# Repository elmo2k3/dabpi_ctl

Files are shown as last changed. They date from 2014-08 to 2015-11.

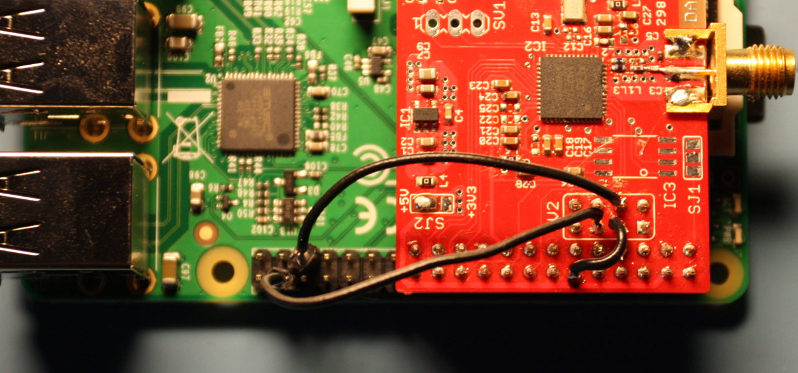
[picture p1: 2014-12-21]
doc/pics/a_b_plus.jpg

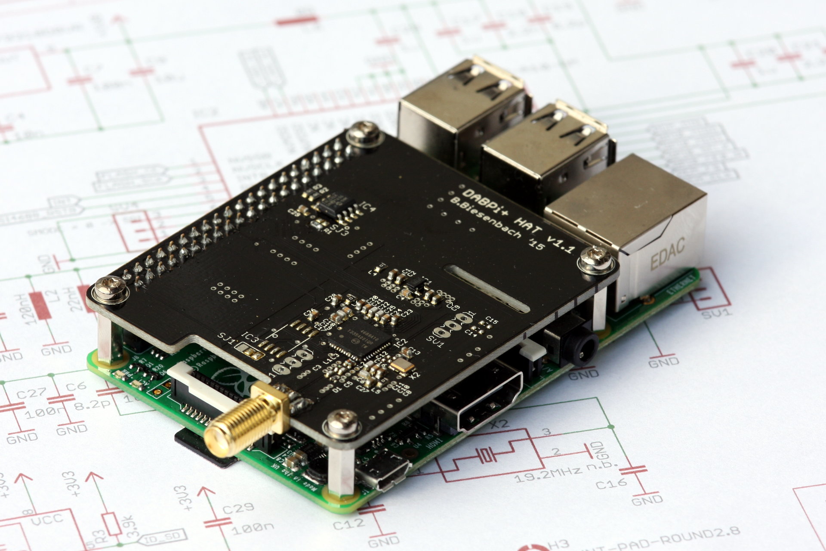
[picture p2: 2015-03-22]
doc/pics/dabpi+_v11_scaled.jpg

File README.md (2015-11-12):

# dabpi_ctl - RPi fm/fmhd/dab receiver control interface

![Image of DABPi+ v11 PCB]
(https://github.com/elmo2k3/dabpi_ctl/blob/master/doc/pics/dabpi+_v11.jpg)
DABPi+ for Raspberry Pi A+/B+ versions. Pi2 not tested yet.
![Image of DABPi v1 PCB]
(https://github.com/elmo2k3/dabpi_ctl/blob/master/doc/pics/dabpi_v1.jpg)
DABPi for older Raspberry Pi A/B versions.

## News

12.4.2015
Works on Pi2 now. New Kernel 3.18.11-v7+ included for Pi2.

## Warning

!!! Firmware files removed due to license issues !!!

This project is beta. A lot of features are still missing.

## Requirements

You need a RPi that has the option to mount the I2S extension header.
![Image of RPi with soldered I2S extension header]
(https://github.com/elmo2k3/dabpi_ctl/blob/master/doc/pics/IMG_0292.JPG)

Get the firmware package for Si4688 from Silabs.

Be sure to enable SPI in raspi-config.

Install wiringPi library. See http://wiringpi.com/download-and-install/

To get the audio you need to install a new kernel. It can be compiled from here
https://github.com/elmo2k3/linux or use the precompiled image. For the precompiled binarys, see the Install section.

## RPi A+/B+ instructions
![Image of RPi B+ with additional cables]
(https://github.com/elmo2k3/dabpi_ctl/blob/master/doc/pics/a_b_plus.jpg)

Connect P5 header pins 3,4,5 to GPIO header pins 12,35,38.

## Install

There is a very simple install script for a fresh raspian now (where there is nothing to be damaged).

```bash
wget https://github.com/elmo2k3/dabpi_ctl/raw/master/install_on_fresh_raspbian.sh
chmod a+x install_on_fresh_raspbian.sh
./install_on_fresh_raspbian.sh
```
This will install the commandline tool to /home/pi/dabpi_ctl

Unpack the firmware files (get it from silabs or ask me) into /home/pi/dabpi_ctl/firmware

### Manual Install

Get and compile the source code:

```bash
git clone https://github.com/elmo2k3/dabpi_ctl
cd dabpi_ctl
make
```
If you want to use the precompiled kernel, it can be found in the kernel/ directory.

```bash
sudo cp kernel/Image /boot/kernel.img
sudo rm -rf /lib/modules
sudo rm -rf /lib/firmware
sudo tar -C / -xvzf kernel/lib.tar.gz
```
Edit /etc/modules
```bash
bcm2708_dmaengine
snd-bcm2835
```
After a reboot load the module.

```bash
sudo modprobe snd-soc-rpi-dabpi
```
You should see this in the kernel log:
```bash
pi@raspberrypi ~/dabpi_ctl $ dmesg | tail -n1
[ 2435.067966] snd-dabpi snd-dabpi.0:  si468x-hifi <-> bcm2708-i2s.0 mapping ok
pi@raspberrypi ~/dabpi_ctl $
```

## Usage

Run dabpi_ctl:

```bash
[bjoern@x200 user_program]$ ./dabpi_ctl
usage: ./dabpi_ctl [-a|-b]
  -a             init DAB mode
  -b             init fm mode
  -c frequency   tune frequency in FM mode
  -d             fm status
  -e             dab status
  -f service     start service of dab service list
  -g             get dab service list
  -i channel     tune to channel in dab frequency list
  -j region      set frequency list
                    0   Baden-Wuertemberg
                    1   Bayern
                    2   Berlin-Brandenburg
                    3   Bremen
                    4   Hamburg
                    5   Hessen
                    6   Mecklenburg-Vorpommern
                    7   Niedersachsen
                    8   Nordrhein-Westfalen
                    9   Rheinland-Pfalz
                    10  Saarland
                    11  Sachsen
                    12  Sachsen-Anhalt
                    13  Schleswig-Holstein
                    14  Thueringen
                    15  Suedtirol (Italien)
                    16  Schweiz
  -k region      scan frequency list
  -l up|down     fm seek next station
  -m             fm rds status
  -n             dab get audio info
  -o             dab get subchannel info
  -s             get sys state (fm,dab,am...)
  -h             this help
```

### Audio output

To test audio output, redirect it from capture to playback device:

```bash
alsaloop -C hw:1,0
```
Stream audio to another linux machine over ssh:

```bash
ssh pi@PI-IP-ADDRESS 'arecord -D hw:1,0 -f dat -' | aplay -f dat -
```

### Examples

Enter fm mode:

```bash
pi@raspberrypi ~/dabpi_ctl $ sudo ./dabpi_ctl -b
si46xx_init_mode_fm()
si46xx_get_sys_state answer: 800000c001ff
si46xx_get_part_info answer: 800000c0000000005012000000005012000000000100
[...]
si46xx_fm_tune_freq(98500)
808000c0
pi@raspberrypi ~/dabpi_ctl $
```

Tune to radio station 106.700MHz:

```bash
pi@raspberrypi ~/dabpi_ctl $ sudo ./dabpi_ctl -c 106700
si46xx_fm_tune_freq(106700)
808000c0
pi@raspberrypi ~/dabpi_ctl $
```

Enter DAB mode and scan all channels in the list for NRW:

```bash
pi@raspberrypi ~/dabpi_ctl $ sudo ./dabpi_ctl -a -k 8
si46xx_init_mode_dab()
[...]
si46xx_dab_tune_freq(0): 818000c0
si46xx_dab_digrad_status(): Channel 0: ACQ: 1 RSSI: 45 SNR: -10 Name: DR Deutschland
si46xx_dab_tune_freq(1): 818000c0
si46xx_dab_digrad_status(): Channel 1: ACQ: 1 RSSI: 41 SNR: -10 Name: Radio fuer NRW
pi@raspberrypi ~/dabpi_ctl $
```

Select DAB channel:

```bash
pi@raspberrypi ~/dabpi_ctl $ sudo ./dabpi_ctl -i 1
si46xx_dab_tune_freq(0): 818000c0
pi@raspberrypi ~/dabpi_ctl $
```

Get ensemble information:

```bash
pi@raspberrypi ~/dabpi_ctl $ sudo ./dabpi_ctl -g
si46xx_dab_get_digital_service_list()
List size:     370
List version:  227
Services:      13
Num:  0  Service ID: e0d01005  Service Name: WDR-INFO          Component ID: 49162
                                                               Component ID: 49162
Num:  1  Service ID:     109d  Service Name: Domradio          Component ID: 12
                                                               Component ID: 0
Num:  2  Service ID: e0d01006  Service Name: WDR-TPEG          Component ID: 49163
                                                               Component ID: 0
Num:  3  Service ID:     d394  Service Name: WDR 4             Component ID: 14
                                                               Component ID: 0
Num:  4  Service ID:     df92  Service Name: VERA              Component ID: 8
                                                               Component ID: 0
Num:  5  Service ID:     d391  Service Name: 1LIVE             Component ID: 1
                                                               Component ID: 0
Num:  6  Service ID:     d395  Service Name: WDR 5             Component ID: 4
                                                               Component ID: 0
Num:  7  Service ID:     d496  Service Name: FUNKHAUS EUROPA   Component ID: 5
                                                               Component ID: 0
Num:  8  Service ID: e0d01004  Service Name: WDR-EPG           Component ID: 49161
                                                               Component ID: 0
Num:  9  Service ID:     df95  Service Name: KinderRadioKanal  Component ID: 2
                                                               Component ID: 0
Num: 10  Service ID:     df91  Service Name: 1LIVE diggi       Component ID: 3
                                                               Component ID: 0
Num: 11  Service ID:     1462  Service Name: RADIO IMPALA      Component ID: 13
                                                               Component ID: 0
Num: 12  Service ID:     d392  Service Name: WDR 2             Component ID: 7
                                                               Component ID: 0
pi@raspberrypi ~/dabpi_ctl $
```

Start one of the services in ensemble:

```bash
pi@raspberrypi ~/dabpi_ctl $ sudo ./dabpi_ctl -f 5
si46xx_dab_get_digital_service_list()
List size:     370
List version:  227
Services:      13
Num:  0  Service ID: e0d01005  Service Name: WDR-INFO          Component ID: 49162
                                                               Component ID: 49162
[...]
Starting service 1LIVE            d391 1
pi@raspberrypi ~/dabpi_ctl $
```

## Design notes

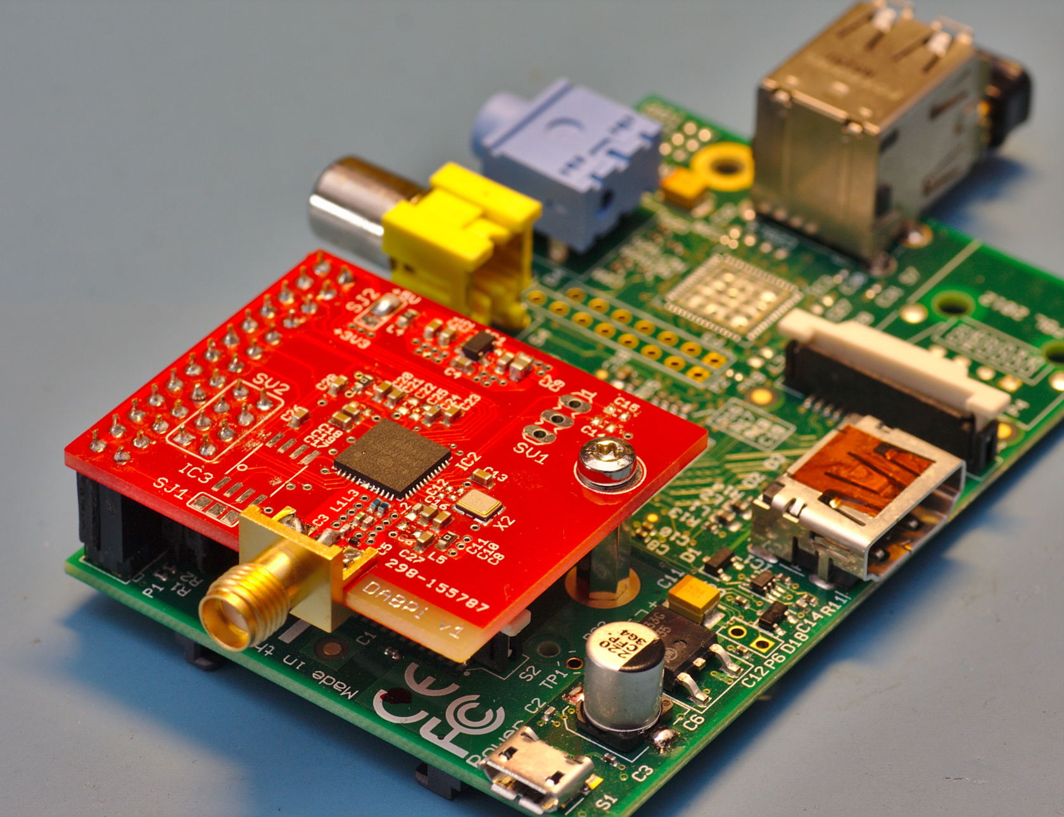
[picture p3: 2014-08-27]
doc/pics/dabpi_v1.jpg

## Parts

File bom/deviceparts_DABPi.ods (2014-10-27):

#name | description | footprint | total_mount_quantity | suppliers | supplierpartnrs | single_prices | total_prices
0R 0402 | MCMR04X000 PTL | R_0603 | 1 | Farnell | 2072513 | $0.01 | $0.01
10nF 0603 25V X7R | MC0603B103K250CT | C_0603 | 1 | Farnell | 1759022 | $0.01 | $0.01
10uF 0603 6.3V X5R | C0603C106M9PACTU | C_0603 | 1 | Farnell | 1288201 | $0.23 | $0.23
120NH 110MA 0402 |  | L_0402 | 1 | Digikey,Farnell | 490-4091-1-ND,2212473 | $0.23,$0.11 | $0.23,$0.11
150pF 0603 | MC0603N151J500CT | C_0603 | 4 | Farnell | 1759068 | $0.00 | $0.00
18NH 300MA 0402 |  | L_0402 | 1 | Digikey,Farnell | 490-2626-1-ND,1343084 | $0.05,$0.06 | $0.05,$0.06
19.2MHZ,3.2 X 2.5 MM | CRYSTAL 19.2MHZ 10PF SMD |  | 1 | Digikey,Farnell | 300-8228-1-ND,1842063 | $1.37,$0.73 | $1.37,$0.73
2.2nF 0603 50V X7R | MC0603B222K500CT | C_0603 | 4 | Farnell | 1759093 | $0.01 | $0.04
22NH 3% 0402 |  | L_0402 | 1 | Digikey,Farnell | 490-6788-1-ND,1711784 | $0.24,$0.05 | $0.24,$0.05
8.2pF 0603 50V C0G | C0603C829C5GACTU | C_0603 | 7 | Farnell | 1865471 | $0.01 | $0.07
Abstandshalter Hex M2.5 11MM |  |  | 1 | Farnell | 1466760 | $0.34 | $0.34
DABPi v1Leiterkarte |  |  | 1 | Iteadstudio | 2 | $2.00 | $2.00
ESD9L5.0ST5G | TVS ESD PROT ELT 5V SOD-923 | SOD923 | 1 | Digikey,Farnell | ESD9L5.0ST5GOSCT-ND,1651639 | -,$0.42 | -,$0.42
SI4688-A10-GM |  | QFN48 | 1 | Arrow | SI4688-A10-GM | $10.00 | $10.00
SMA Buchse PCB |  |  | 1 | Digikey,Farnell | CONSMA003.062-ND,1909295 | $2.77,$3.35 | $2.77,$3.35
TPS79318DBVR | IC REG LDO 1.8V 0.2A SOT23-5 | SOT23-5 | 1 | Digikey,Farnell | 296-12155-1-ND,1652374 | $0.69,$0.91 | $0.69,$0.91

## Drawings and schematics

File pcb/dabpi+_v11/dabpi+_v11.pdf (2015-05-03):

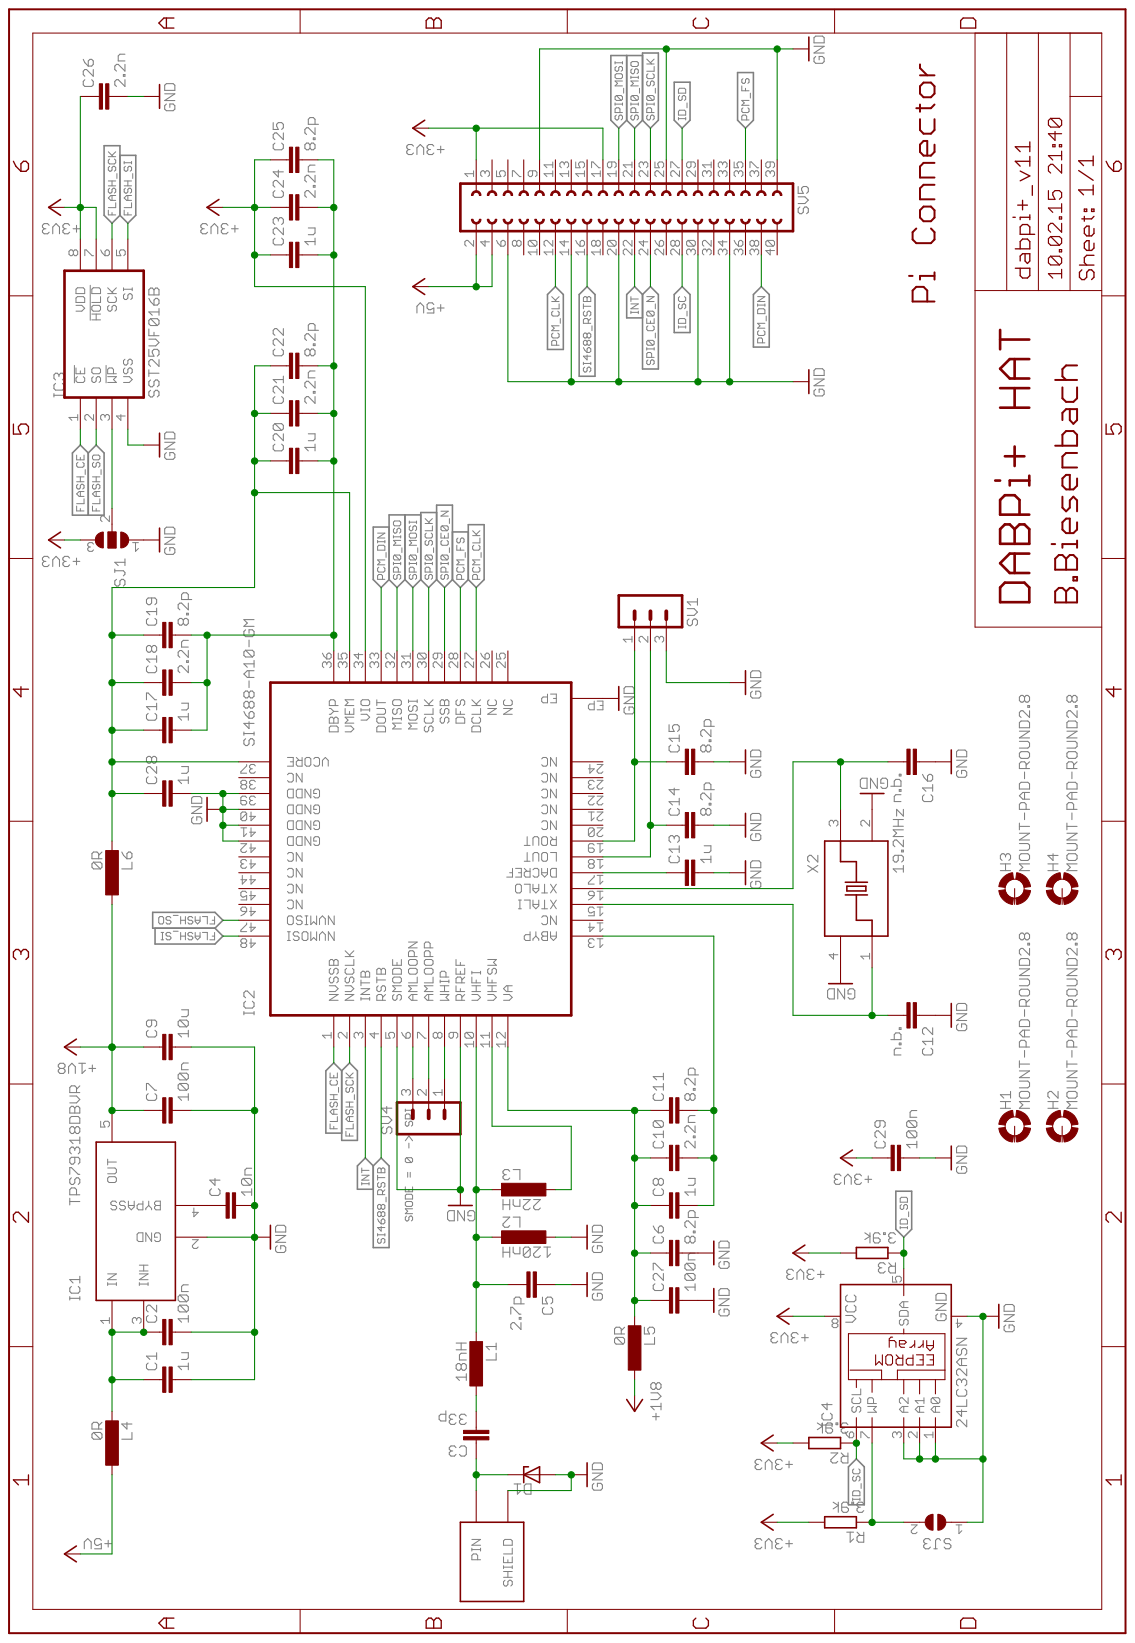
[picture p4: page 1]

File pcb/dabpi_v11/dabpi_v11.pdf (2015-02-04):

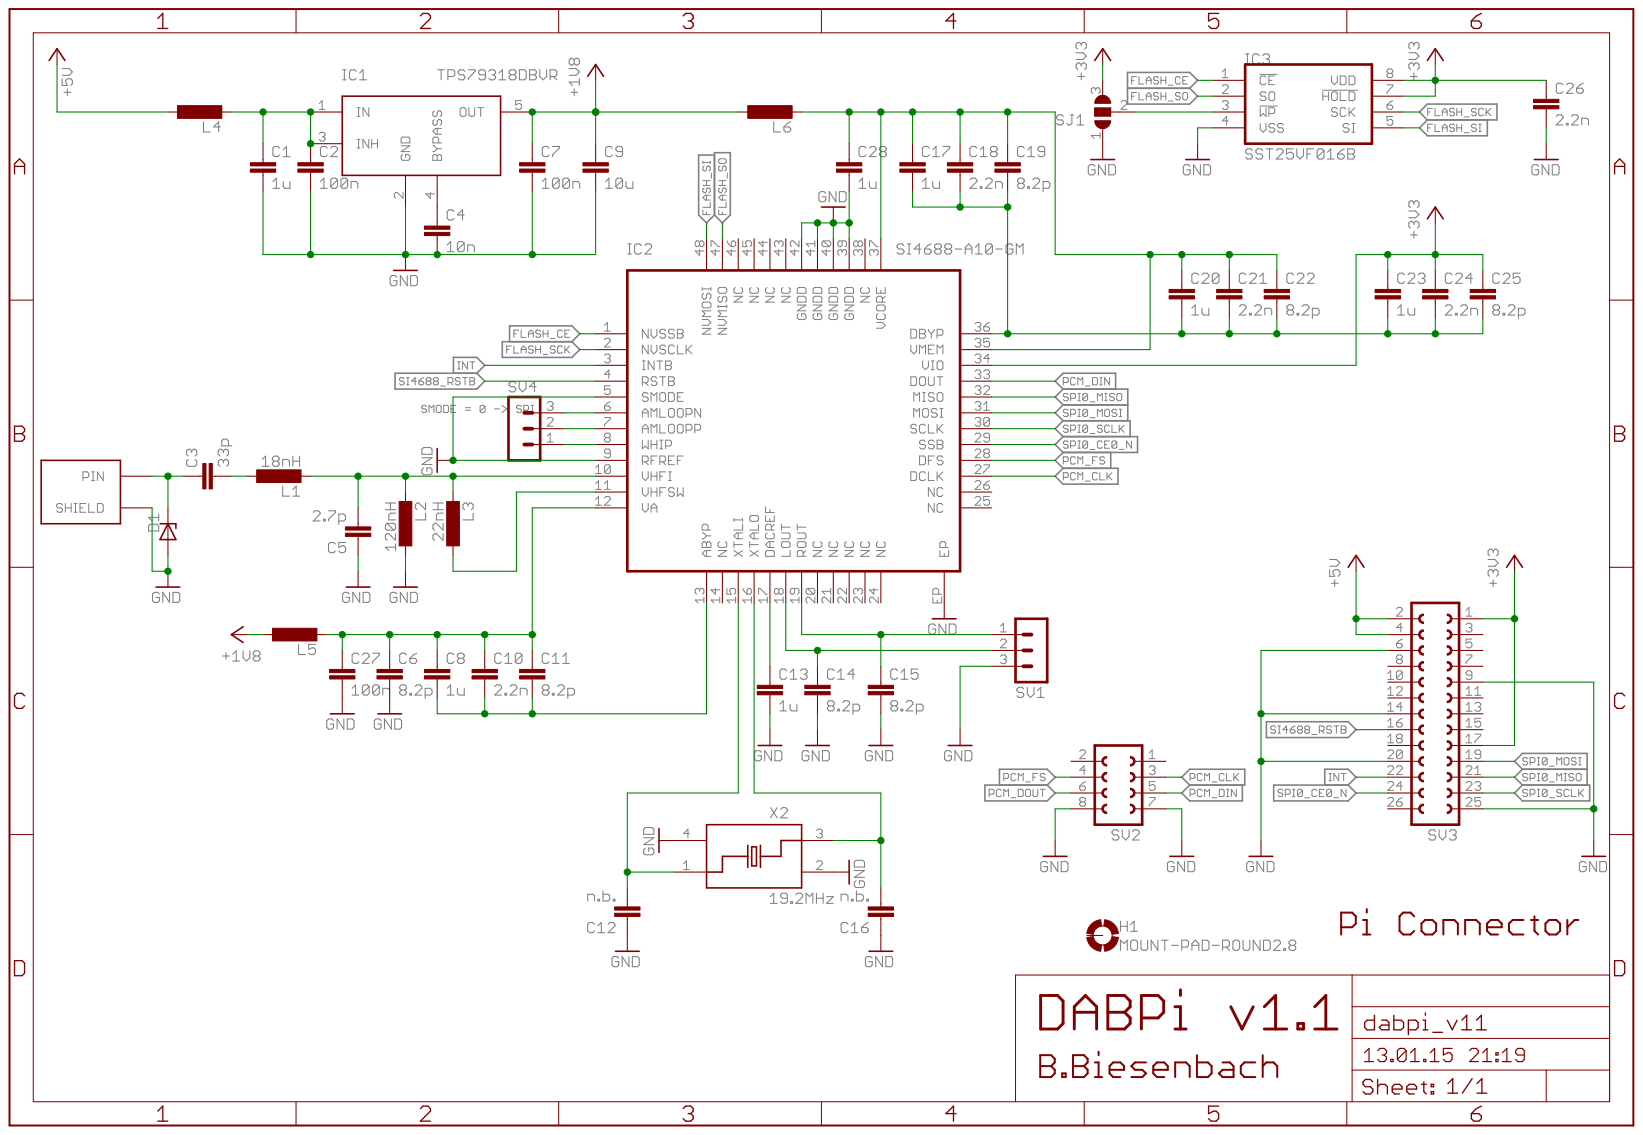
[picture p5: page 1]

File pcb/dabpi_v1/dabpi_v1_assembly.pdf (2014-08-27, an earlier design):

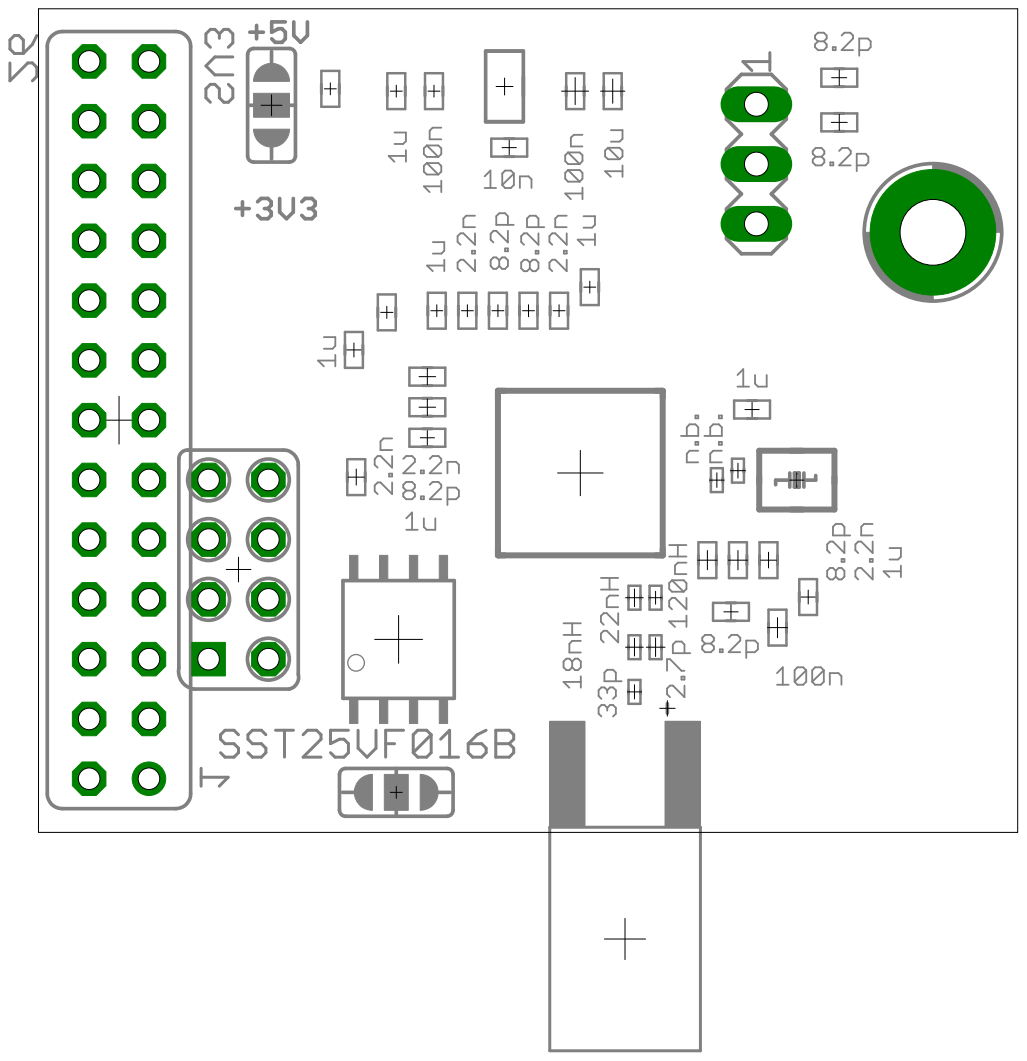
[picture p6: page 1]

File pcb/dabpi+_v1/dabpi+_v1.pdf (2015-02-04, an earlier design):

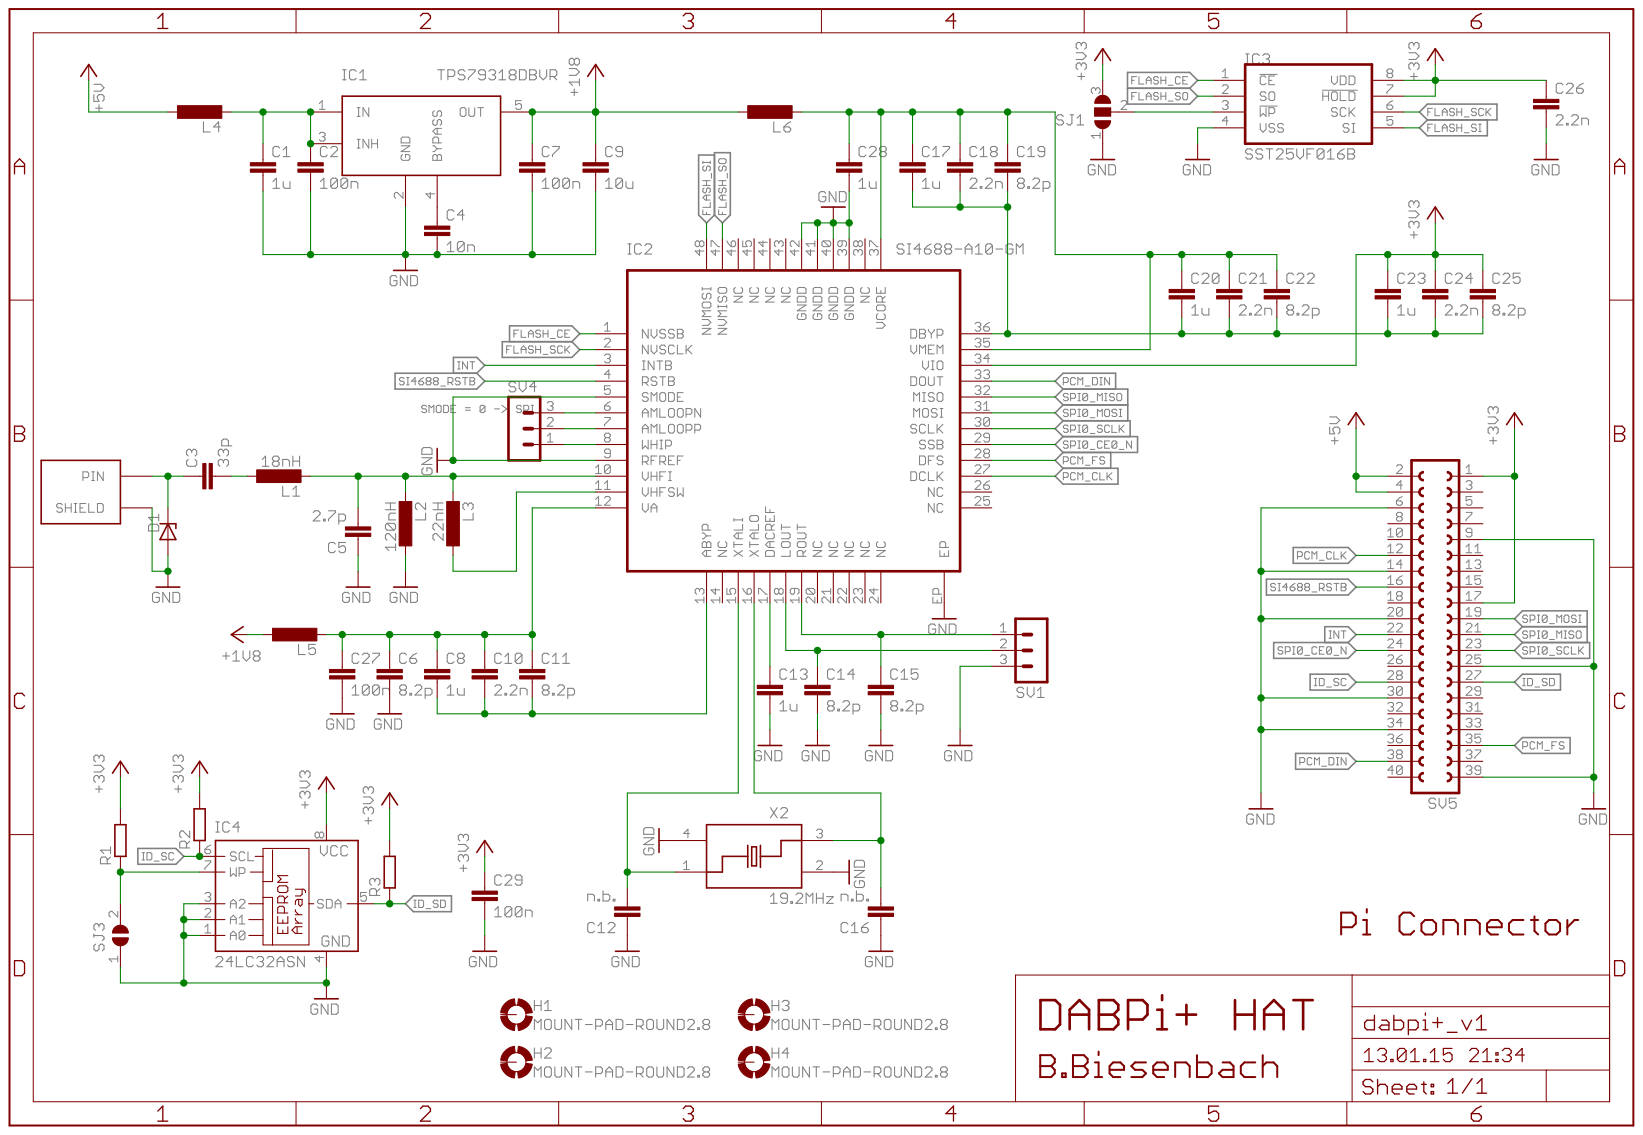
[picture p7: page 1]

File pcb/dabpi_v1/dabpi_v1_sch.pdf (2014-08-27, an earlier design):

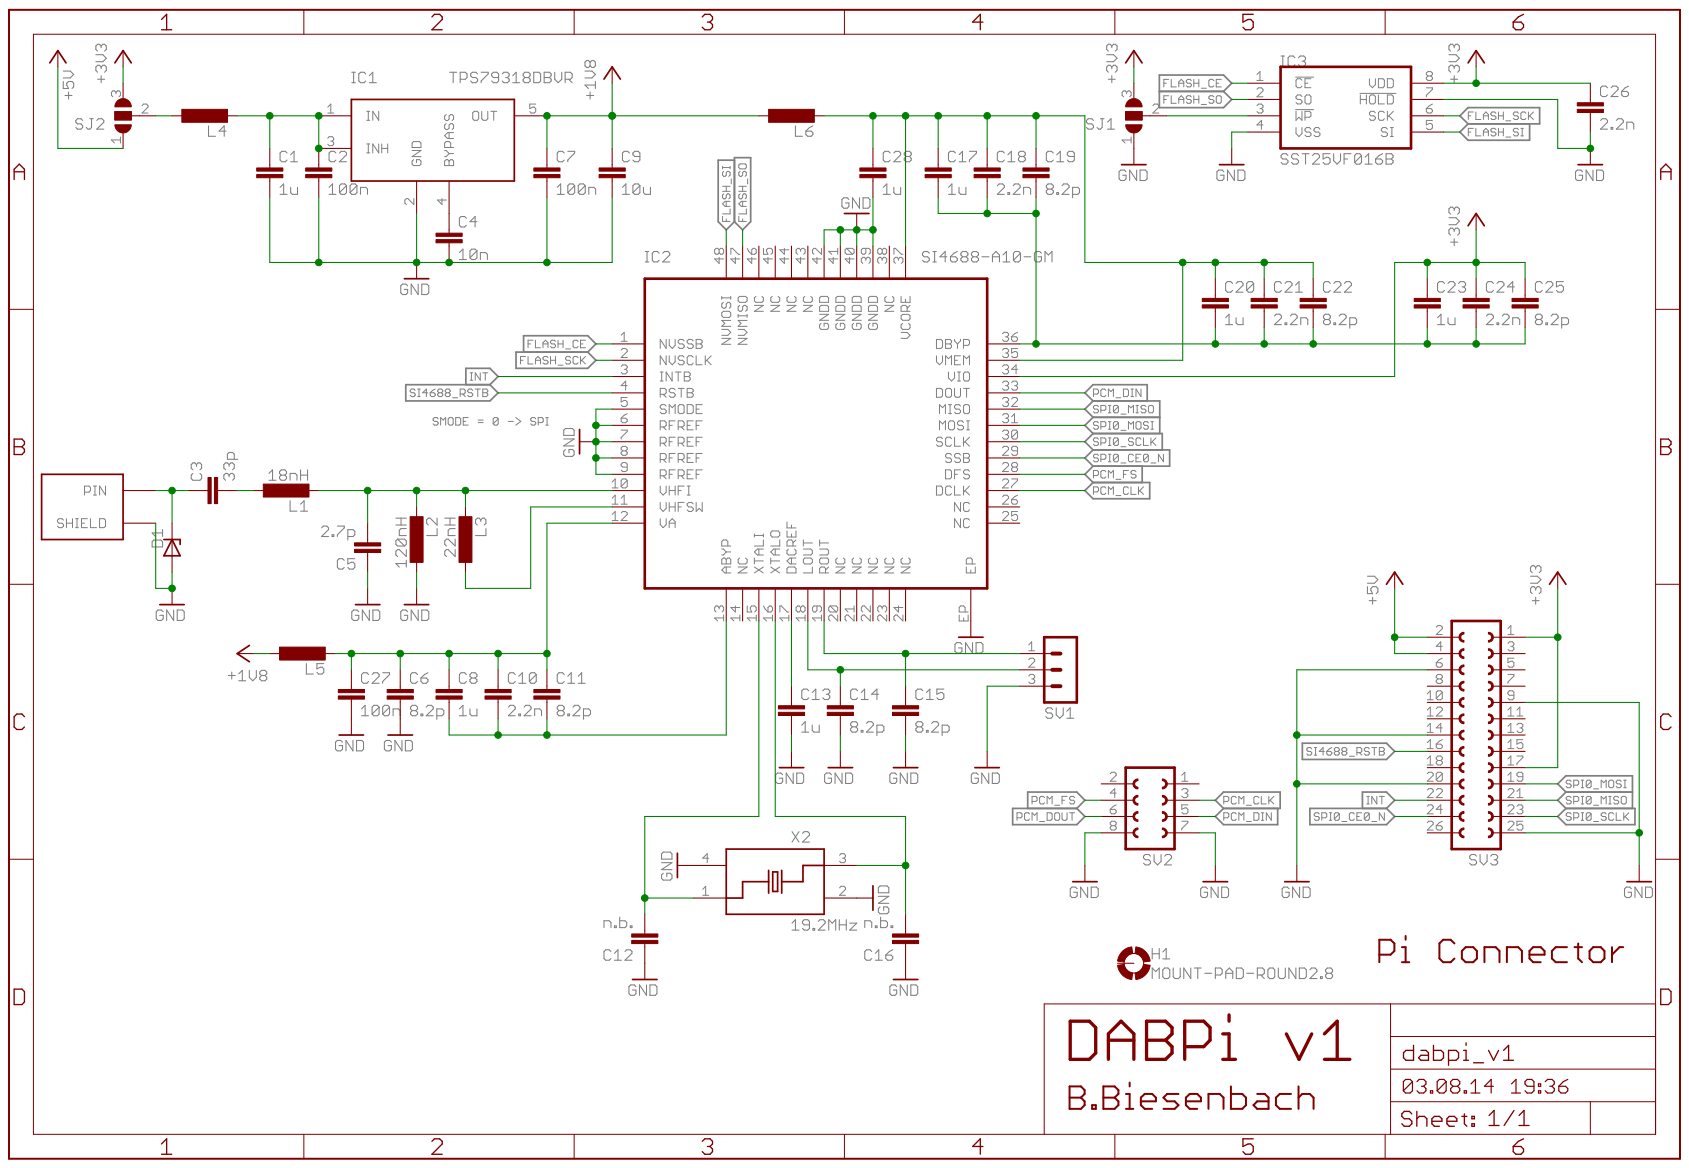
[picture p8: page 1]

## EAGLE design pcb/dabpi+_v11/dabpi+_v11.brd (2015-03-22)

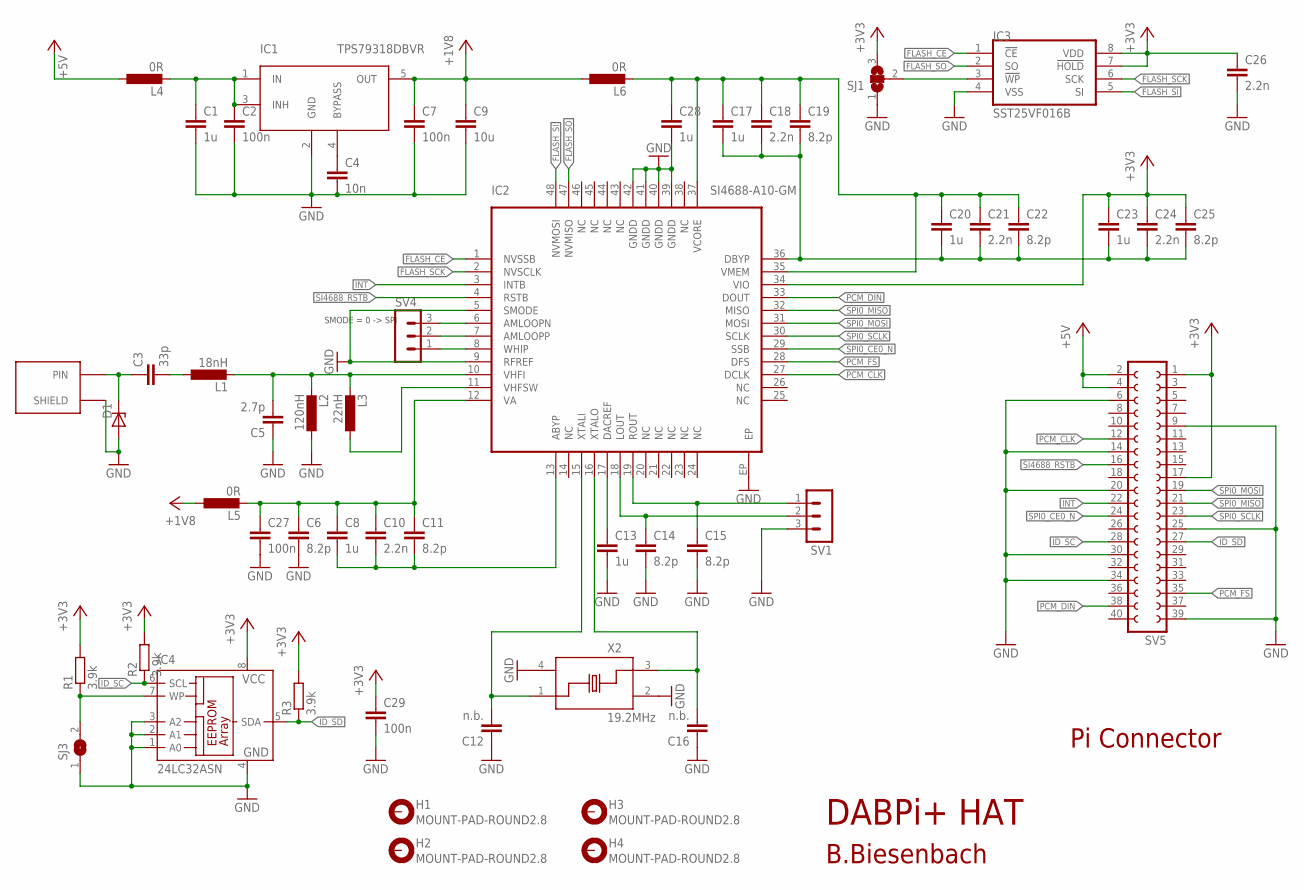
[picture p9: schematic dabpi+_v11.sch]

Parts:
C1, C8, C13, C17, C20, C23, C28: 1u; SMD0603
C2, C7, C27, C29: 100n; SMD0603
C3: 33p; SMD0402
C4: 10n; SMD0603
C5: 2.7p; SMD0402
C6, C11, C14, C15, C19, C22, C25: 8.2p; SMD0603
C9: 10u; SMD0603
C10, C18, C21, C24, C26: 2.2n; SMD0603
C12, C16: n.b.; SMD0402
D1: ESD9L5.0; SOD923
H1, H2, H3, H4: MOUNT-PAD-ROUND2.8; 2,8-PAD
IC1: TPS79318DBVR; SOT23-5
IC2: SI4688-A10-GM; QFN48
IC3: SST25VF016B; SO08
IC4: 24LC32ASN; SO-08
L1: 18nH; SMD0402
L2: 120nH; SMD0402
L3: 22nH; SMD0402
L4, L5, L6: 0R; SMD0603
R1, R2, R3: 3.9k; SMD0603
SJ1: SJ2W; SJ_2
SJ3: SJ
SV1, SV4: MA03-1
SV5: FE20-2
X1: SMA_LP_1.57MM
X2: 19.2MHz; XTAL_3.2X2.5

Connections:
+1V8: C7.1, C9.1, IC1.5 (OUT), L5.1, L6.1
+3V3: C23.1, C24.1, C25.1, C26.1, C29.1, IC2.34 (VIO), IC3.7 (!HOLD), IC3.8 (VDD), IC4.8 (VCC), R1.2, R2.2, R3.2, SJ1.3, SV5.1, SV5.17
+5V: L4.1, SV5.2, SV5.4
FLASH_CE: IC2.1 (NVSSB), IC3.1 (!CE)
FLASH_SCK: IC2.2 (NVSCLK), IC3.6 (SCK)
FLASH_SI: IC2.48 (NVMOSI), IC3.5 (SI)
FLASH_SO: IC2.47 (NVMISO), IC3.2 (SO)
GND: C1.2, C2.2, C4.2, C5.1, C6.2, C7.2, C9.2, C12.1, C13.2, C14.2, C15.2, C16.1, C26.2, C27.2, C28.2, C29.2, D1.A, IC1.2 (GND), IC2.5 (SMODE), IC2.9 (RFREF), IC2.39 (GNDD), IC2.40 (GNDD), IC2.41 (GNDD), IC2.42 (GNDD), IC2.EP, IC3.4 (VSS), IC4.1 (A0), IC4.2 (A1), IC4.3 (A2), IC4.4 (GND), L2.1, SJ1.1, SJ3.1, SV1.3, SV5.6, SV5.9, SV5.14, SV5.20, SV5.25, SV5.30, SV5.34, SV5.39, X1.GND (SHIELD), X1.GND@1 (SHIELD), X1.GND@2 (SHIELD), X1.GND@3 (SHIELD), X2.2 (GND), X2.4 (GND)
ID_SC: IC4.6 (SCL), R2.1, SV5.28
ID_SD: IC4.5 (SDA), R3.1, SV5.27
INT: IC2.3 (INTB), SV5.22
LDO_IN: C1.1, C2.1, IC1.1 (IN), IC1.3 (INH), L4.2
unnamed: C3.2, L1.1
unnamed: C5.2, IC2.10 (VHFI), L1.2, L2.2, L3.2
unnamed: IC2.11 (VHFSW), L3.1
unnamed: C8.2, C10.2, C11.2, IC2.13 (ABYP)
unnamed: C17.2, C18.2, C19.2, C20.2, C21.2, C22.2, C23.2, C24.2, C25.2, IC2.36 (DBYP)
unnamed: C12.2, IC2.15 (XTALI), X2.1
unnamed: C16.2, IC2.16 (XTALO), X2.3
unnamed: C13.1, IC2.17 (DACREF)
unnamed: IC3.3 (!WP), SJ1.2
unnamed: C4.1, IC1.4 (BYPASS)
unnamed: C6.1, C8.1, C10.1, C11.1, C27.1, IC2.12 (VA), L5.2
unnamed: IC2.6 (AMLOOPN), SV4.3
unnamed: C17.1, C18.1, C19.1, C20.1, C21.1, C22.1, C28.1, IC2.35 (VMEM), IC2.37 (VCORE), L6.2
unnamed: IC2.7 (AMLOOPP), SV4.2
unnamed: IC2.8 (WHIP), SV4.1
unnamed: IC4.7 (WP), R1.1, SJ3.2
PCM_CLK: IC2.27 (DCLK), SV5.12
PCM_DIN: IC2.33 (DOUT), SV5.38
PCM_FS: IC2.28 (DFS), SV5.35
RF_IN: C3.1, D1.K (C), X1.PIN
SI4688_LOUT: C14.1, IC2.18 (LOUT), SV1.2
SI4688_ROUT: C15.1, IC2.19 (ROUT), SV1.1
SI4688_RSTB: IC2.4 (RSTB), SV5.16
SPI0_CE0_N: IC2.29 (SSB), SV5.24
SPI0_MISO: IC2.32 (MISO), SV5.21
SPI0_MOSI: IC2.31 (MOSI), SV5.19
SPI0_SCLK: IC2.30 (SCLK), SV5.23

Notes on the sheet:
DABPi+ HAT
SMODE = 0 -> SPI
Pi Connector
B.Biesenbach

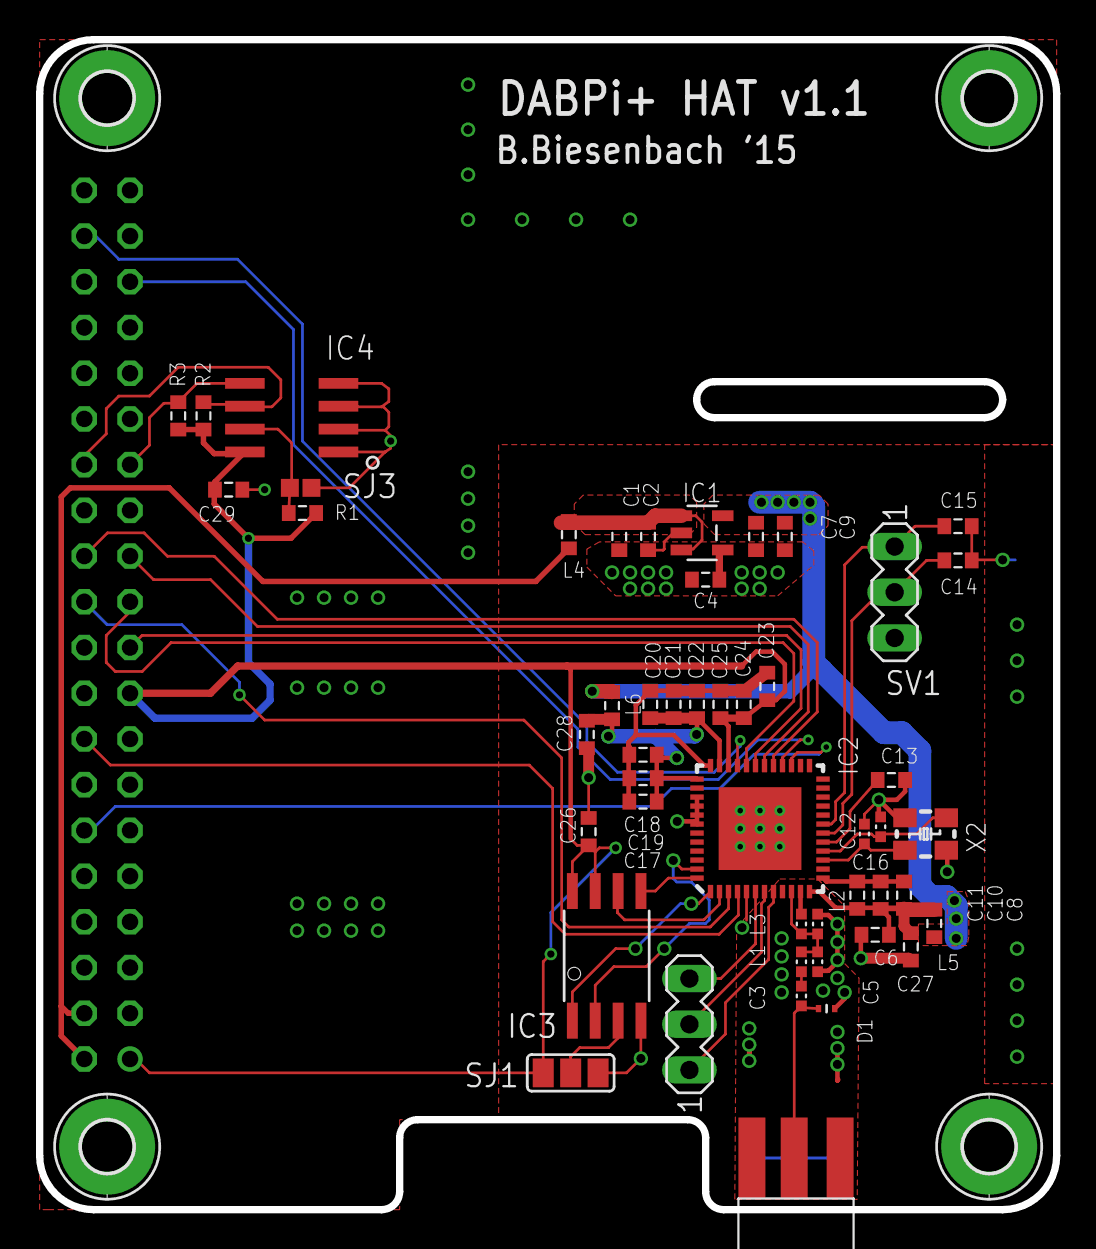
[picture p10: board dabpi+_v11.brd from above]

Board: 2 copper layers, 56.5 x 65.0 mm, 54 parts (1 on the bottom side), 39 nets.

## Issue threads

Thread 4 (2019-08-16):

Compatible Hardware

linuxchris12, 2019-08-16:
In case that anyone is searching for a Raspberry Extension Board which is compatible to this project (although some details are different), it can be obtained here:

https://ugreen.eu/product/ugreen-dab-board/

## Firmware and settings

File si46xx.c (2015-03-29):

/* 
 * dabpi_ctl - raspberry pi fm/fmhd/dab receiver board control interface
 * Copyright (C) 2014  Bjoern Biesenbach <bjoern@bjoern-b.de>
 * 
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
 * You should have received a copy of the GNU General Public License
 * along with this program.  If not, see <http://www.gnu.org/licenses/>.
 */
#include <stdio.h>
#include <stdlib.h>
#include <string.h>
#ifdef __arm__
#include <wiringPi.h>
#include <wiringPiSPI.h>
#endif
#include "si46xx.h"
//#include "dab_radio_3_2_7.h"

#define msleep(x) usleep(x*1000)

#ifdef __arm__
#define CS_LOW() digitalWrite(10, LOW)
#define CS_HIGH() digitalWrite(10, HIGH)

#define RESET_LOW() digitalWrite(4, LOW)
#define RESET_HIGH() digitalWrite(4, HIGH)

#define SPI_Write(data,len) wiringPiSPIDataRW(0,data,len)
#else
#define CS_LOW()
#define CS_HIGH()
#define RESET_LOW()
#define RESET_HIGH()
#define SPI_Write(data,len)
#endif
//
//#define msleep(x) HAL_Delay(x)
//#define SPI_Write(data,len) HAL_SPI_Transmit(&hspi1,data,len,1000)
//#define CS_LOW() GPIOA->BSRRH = SI46XX_PIN_NSS
//#define CS_HIGH() GPIOA->BSRRL = SI46XX_PIN_NSS
//#define RESET_LOW() GPIOB->BSRRH = GPIO_PIN_8
//#define RESET_HIGH() GPIOB->BSRRL = GPIO_PIN_8
//
uint8_t dab_num_channels;

void print_hex_str(uint8_t *str, uint16_t len)
{
	uint16_t i;
	printf("0x");
	for(i=0;i<len;i++){
		printf("%02x",(int)str[i]);
	}
	printf("\r\n");
}

static void si46xx_write_host_load_data(uint8_t cmd,
		const uint8_t *data,
		uint16_t len)
{

	uint8_t zero_data[3];

	zero_data[0] = 0;
	zero_data[1] = 0;
	zero_data[2] = 0;
	CS_LOW();
	SPI_Write(&cmd,1);
	SPI_Write(zero_data,3);
	SPI_Write((uint8_t*)data,len);
	CS_HIGH();
}

static void si46xx_read(uint8_t *data, uint8_t cnt)
{
	uint8_t zero = 0;
	uint8_t timeout;

	timeout = 100; // wait for CTS
	while(--timeout){
		CS_HIGH();
		msleep(1); // make sure cs is high for 20us
		CS_LOW();
		zero = 0;
		SPI_Write(&zero,1); // read status register (we are working without interrupts)
		SPI_Write(data,cnt); // read data
		CS_HIGH();
		msleep(1); // make sure cs is high for 20us
		if(data[0] & 0x80)
			break;
	}
}

static void si46xx_write_data(uint8_t cmd,
		uint8_t *data,
		uint16_t len)
{
	uint8_t timeout;
	uint8_t buf[4];

	timeout = 100; // wait for CTS
	while(--timeout){
		si46xx_read(buf,4);
		if(buf[0] & 0x80)
			break;
	}

	CS_LOW();
	SPI_Write(&cmd,1);
	SPI_Write(data,len);
	CS_HIGH();
}

static uint16_t si46xx_read_dynamic(uint8_t *data)
{
	uint8_t zero = 0;
	uint16_t cnt;

	CS_HIGH();
	msleep(1); // make sure cs is high for 20us
	CS_LOW();
	SPI_Write(&zero,1);
	SPI_Write(data,6);
	cnt = ((uint16_t)data[5]<<8) | (uint16_t)data[4];
	if(cnt > 3000) cnt = 0;
	SPI_Write(&data[6],cnt);
	CS_HIGH();
	msleep(1); // make sure cs is high for 20us

	return cnt + 6;
}

void si46xx_get_sys_state()
{
	uint8_t zero = 0;
	char buf[6];
	uint8_t mode;

	si46xx_write_data(SI46XX_GET_SYS_STATE,&zero,1);
	si46xx_read(buf,6);
	mode = buf[4];
	printf("si46xx_get_sys_state answer: ");
	print_hex_str(buf,6);
	printf("Current mode: \n");
	switch(mode)
	{
		case 0: printf("Bootloader is active\n"); break;
		case 1: printf("FMHD is active\n"); break;
		case 2: printf("DAB is active\n"); break;
		case 3: printf("TDMB or data only DAB image is active\n"); break;
		case 4: printf("FMHD is active\n"); break;
		case 5: printf("AMHD is active\n"); break;
		case 6: printf("AMHD Demod is active\n"); break;
		default: break;
	}
}

static void si46xx_get_part_info()
{
	uint8_t zero = 0;
	char buf[22];

	si46xx_write_data(SI46XX_GET_PART_INFO,&zero,1);
	si46xx_read(buf,22);
	printf("si46xx_get_part_info answer: ");
	print_hex_str(buf,22);
}

void si46xx_periodic()
{
	char buf[4];
	si46xx_read(buf,4);
}


void si46xx_dab_start_digital_service(uint32_t service_id,
		uint32_t comp_id)
{
	uint8_t data[11];
	char buf[5];

	data[0] = 0;
	data[1] = 0;
	data[2] = 0;
	data[3] = service_id & 0xFF;
	data[4] = (service_id >>8) & 0xFF;
	data[5] = (service_id >>16) & 0xFF;
	data[6] = (service_id >>24) & 0xFF;
	data[7] = comp_id & 0xFF;
	data[8] = (comp_id >> 8) & 0xFF;
	data[9] = (comp_id >> 16) & 0xFF;
	data[10] = (comp_id >> 24) & 0xFF;

	si46xx_write_data(SI46XX_DAB_START_DIGITAL_SERVICE,data,11);
	si46xx_read(buf,5);
}

static si46xx_swap_services(uint8_t first, uint8_t second)
{
	struct dab_service_t tmp;

	memcpy(&tmp,&dab_service_list.services[first],sizeof(tmp));
	memcpy(&dab_service_list.services[first],
			&dab_service_list.services[second] ,sizeof(tmp));
	memcpy(&dab_service_list.services[second],&tmp ,sizeof(tmp));
}

static si46xx_sort_service_list(void)
{
	uint8_t i,p,swapped;

	swapped = 0;
	for(i=dab_service_list.num_services;i>1;i--){
		for(p=0;p<i-1;p++){
			if(dab_service_list.services[p].service_id >
					dab_service_list.services[p+1].service_id){
				si46xx_swap_services(p,p+1);
				swapped = 1;
			}
		}
		if(!swapped)
			break;
	}
}

static void si46xx_dab_parse_service_list(uint8_t *data, uint16_t len)
{
	uint16_t remaining_bytes;
	uint16_t pos;
	uint8_t service_num;
	uint8_t component_num;
	uint8_t i;

	if(len<6)
		return; // no list available? exit
	if(len >= 9){
		dab_service_list.list_size = data[5]<<8 | data[4];
		dab_service_list.version = data[7]<<8 | data[6];
		dab_service_list.num_services = data[8];
	}
	// 9,10,11 are align pad
	pos = 12;
	if(len <= pos)
		return; // no services? exit

	remaining_bytes = len - pos;
	service_num = 0;
	// size of one service with zero component: 24 byte
	// every component + 4 byte
	while(service_num < dab_service_list.num_services){
		dab_service_list.services[service_num].service_id =
			data[pos+3]<<24 |
			data[pos+2]<<16 |
			data[pos+1]<<8 |
			data[pos];
		component_num = data[pos+5] & 0x0F;
		dab_service_list.services[service_num].num_components = component_num;
		memcpy(dab_service_list.services[service_num].service_label,
				&data[pos+8],16);
		dab_service_list.services[service_num].service_label[16] = '\0';
		for(i=0;i<component_num;i++){
			dab_service_list.services[service_num].component_id[i] =
				data[pos+25] << 8 |
				data[pos+24];
			pos += 4;
		}
		pos +=24;
		service_num++;
	}
	si46xx_sort_service_list();
}

void si46xx_dab_get_ensemble_info()
{
	char buf[22];
	char data;
	uint8_t timeout;
	char label[17];

	//data[0] = (1<<4) | (1<<0); // force_wb, low side injection
	data = 0;

	si46xx_write_data(SI46XX_DAB_GET_ENSEMBLE_INFO,&data,1);
	timeout = 10;
	while(--timeout){ // completed with CTS
		si46xx_read(buf,22);
		if(buf[0] & 0x80)
			break;
	}
	memcpy(label,&buf[6],16);
	label[16] = '\0';
	printf("Name: %s",label);
}
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

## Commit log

2014-08-25 simple install script
    very simple script to install wiringPi, dabpi_ctl
    and the new kernel on a fresh raspbian
2014-08-27 picture of pcb added
2014-08-27 pcb: schematic and board added
    [dabpi_v1.brd, dabpi_v1.sch]
2014-10-27 added bill of material
    [deviceparts_DABPi.ods]
2015-02-04 pcb layout updates
    added board dabpi+ for RPi B+, updated dabpi board
    both boards are now prepared for si4689
    [dabpi+_v1.brd, dabpi+_v1.sch, dabpi_v1.brd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]
2015-03-22 New DABPi+ version 1.1 added
    [dabpi+_v11.brd, dabpi+_v11.sch]
2015-05-03 Added dabpi+_v11 schematic pdf

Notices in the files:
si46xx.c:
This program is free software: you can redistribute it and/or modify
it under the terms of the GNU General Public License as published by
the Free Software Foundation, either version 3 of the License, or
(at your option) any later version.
